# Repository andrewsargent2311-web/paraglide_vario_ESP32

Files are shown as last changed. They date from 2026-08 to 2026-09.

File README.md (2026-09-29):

# Paraglide Vario / Flight Computer (ESP32-S3)

A DIY flight computer for paragliding and paramotoring that costs about **$60 USD** in parts. It has a sunlight-readable screen, a climb/sink beeper (vario), GPS, a barometer, airspace warnings, live ADS-B traffic with spoken voice alerts, weather stations, FANET radio and IGC flight logging.

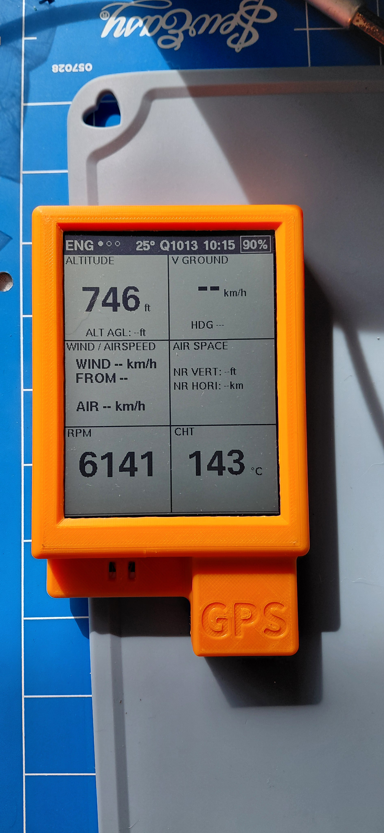
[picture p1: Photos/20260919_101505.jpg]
The finished flight computer


**You do not need any electronics or programming experience.** This guide walks through every step. If you can follow a recipe and are willing to learn to solder a few small parts (or find a friend who can), you can build this.

> ⚠️ **Safety:** This is a hobby project, not a certified flight instrument. Never rely on it as your only source of airspace, altitude or traffic information. Test everything on the ground before you fly with it.

---

## Contents

1. [What it does](#1-what-it-does)
2. [What you need to buy](#2-what-you-need-to-buy)
3. [Tools you need](#3-tools-you-need)
4. [Step 1: Order the circuit board](#step-1-order-the-circuit-board)
5. [Step 2: 3D print the case](#step-2-3d-print-the-case)
6. [Step 3: Solder the circuit board](#step-3-solder-the-circuit-board)
7. [Step 4: Install the software tools](#step-4-install-the-software-tools)
8. [Step 5: Add your WiFi details](#step-5-add-your-wifi-details)
9. [Step 6: Upload the code](#step-6-upload-the-code)
10. [Step 7: Prepare the SD card](#step-7-prepare-the-sd-card)
11. [Step 8: Assemble everything](#step-8-assemble-everything)
12. [Step 9: First power-on check](#step-9-first-power-on-check)
13. [How to use it](#how-to-use-it)
14. [Voice traffic alerts](#voice-traffic-alerts)
15. [Cloud base estimate](#cloud-base-estimate)
16. [Optional extras](#optional-extras)
17. [Troubleshooting](#troubleshooting)
18. [Using it outside New Zealand](#using-it-outside-new-zealand)
19. [Code layout](#code-layout)
20. [Credits](#credits)

---

## 1. What it does

- **Vario:** beeps faster and higher as you climb, lower tones when you sink
- **Main flight screen:** altitude, height above ground (AGL), ground speed, heading, QNH, battery
- **Airspace:** warns you about nearby controlled airspace from an OpenAIP file
- **Cloud base estimate:** a rough guess of how high the cloud base is, worked out from the temperature, humidity and pressure sensors (see [Cloud base estimate](#cloud-base-estimate))
- **ADS-B page:** shows nearby aircraft on a radar-style display
- **Voice traffic alerts:** when an aircraft comes close, the speaker tells you where it is, e.g. *"Aircraft on your two o'clock, flying north west, at two thousand four hundred feet, one thousand two hundred feet above you, and is eight hundred meters away."* You can switch this to a siren, or turn it off (see [Voice traffic alerts](#voice-traffic-alerts))
- **Weather page:** wind from nearby weather stations (Zephyr) or from FANET
- **FANET:** sends and receives FANET radio messages, with preset messages you can broadcast
- **IGC flight logging** to the SD card, downloadable over WiFi
- **Optional:** connects by Bluetooth to a separate engine meter (RPM, cylinder temperature) for paramotor use

**One button** controls everything (see [How to use it](#how-to-use-it)).

## 2. What you need to buy

| Part | Approx. cost | Notes |
|---|---|---|
| [Waveshare ESP32-S3-RLCD-4.2](https://www.waveshare.com/esp32-s3-rlcd-4.2.htm) | $27 | The "brain", screen, speaker driver, SD slot and battery holder all in one |
| [Adafruit BMP580](https://www.adafruit.com/product/6411) | $8 | Barometer, measures altitude change for the vario |
| [Waveshare LC76G GNSS module](https://www.waveshare.com/lc76g-gnss-module.htm) | $15 | GPS |
| Custom circuit board (PCB) from PCBWay | $5 | See [Step 1](#step-1-order-the-circuit-board) |
| 3D printer filament (PLA) | $5 | Orange in the photos, any colour works |
| microSD card, 8–16 GB | a few $ | Doesn't need to be bigger |
| **HT-RA62 LoRa radio module** | check price | Soldered directly onto the PCB, used for FANET. *Not included in the original $60 estimate.* |
| **18650 lithium battery** | check price | Fits in the holder on the Waveshare board. Use a good-quality protected cell. |
| **Small speaker** with an MX1.25 2-pin plug | a few $ | Plugs into the Waveshare board's speaker header. Without it there is no vario sound. |
| **USB-C data cable** | | Must carry data, not just charge |

**Small parts for the PCB** (all size 0805 surface-mount):

| Qty | Part |
|---|---|
| 2 | 100 nF capacitor |
| 2 | 10 µF capacitor |
| 1 | 10 kΩ resistor |

You will also need some pin headers and/or sockets to connect the Waveshare board, BMP580 and GPS module to the PCB. The exact layout is shown in the [KiCad project](PCB%20files/ESP32%20vario_PCB_layout/).

**Total: roughly $60–80 USD** plus shipping, depending on the items in bold.

> **Tip:** Buy everything from the same order window if you can. PCBs from PCBWay usually arrive in a couple of weeks, so order that first.

## 3. Tools you need

- **Soldering iron** with a fine tip, solder and flux (for the tiny 0805 parts and the LoRa module). A hot-air station makes this easier but is not required.
- **Tweezers** (for the small parts)
- **A 3D printer**, or use a print service / friend with one
- **A computer** (Windows, Mac or Linux) with a USB port
- **A microSD card reader**
- Small screwdrivers, and wire cutters

**Never soldered before?** The only genuinely fiddly parts are the 0805 capacitors/resistor and the HT-RA62 module. Watch a couple of "how to solder SMD 0805" videos and practise on a spare board first, or ask a local maker space or electronics-savvy friend to do just those parts.

**Time:** allow a weekend. The 3D printing (about 9.5 hours total) runs by itself.

---

## Step 1: Order the circuit board

The circuit board (PCB) connects all the modules together so you don't have to wire anything by hand.

1. Go to [pcbway.com](https://www.pcbway.com) and choose **Instant Quote**.
2. Upload the file [`PCB files/Gerber Files V2/ESP32 vario-B_PCB_.zip`](PCB%20files/Gerber%20Files%20V2/). It contains all the Gerber and drill files in one zip.
3. Leave the options at their defaults unless you have a preference (it is a simple two-layer board), and place the order.

The original design files (KiCad) are in [`PCB files/ESP32 vario_PCB_layout/`](PCB%20files/ESP32%20vario_PCB_layout/) if you want to modify the board.

## Step 2: 3D print the case

All files are in [`3D print Files/`](3D%20print%20Files/).

| Part | STL file | Print time (0.15 mm PLA, Prusa MK3S) |
|---|---|---|
| Main case | `Flight computer main case.stl` | 5 h 49 m |
| Back plate | `Flight computer back plate.stl` | 2 h 11 m |
| Base plate | `Flight computer base plate.stl` | 1 h 14 m |
| Button | `button.stl` | 8 m |
| Button (short) | `button_Short.stl` | 6 m |
| Button (long) | `button_Long.stl` | 9 m |

- If you have a **Prusa MK3S**, you can print the ready-made G-code in the `Prusa slicer G code` folder.
- For **any other printer**, open the `.stl` files in your printer's slicing software (Cura, PrusaSlicer, Bambu Studio, etc.) and use normal PLA settings at 0.15 mm layer height.
- Print all three buttons; you'll pick whichever length feels best when you assemble it.

## Step 3: Solder the circuit board

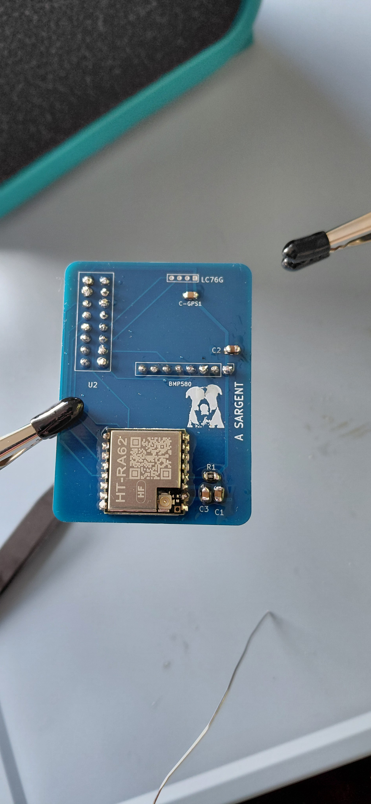
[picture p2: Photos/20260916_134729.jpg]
The PCB with the LoRa module fitted


Work from the smallest parts to the biggest, and take your time. Solder joints should be shiny and cone-shaped, not blobs.

1. **Small surface-mount parts first:** the two 100 nF capacitors, two 10 µF capacitors and the 10 kΩ resistor. The reference labels (C1, C2, C3, C-GPS1, R1) are printed on the board. Use the [parts list](PCB%20files/ESP32%20vario_PCB_layout/ESP32%20vario.csv) to match them.
2. **HT-RA62 LoRa module (U1):** solder this onto its pads on the board. Check the orientation using the silkscreen and the photo above. Double-check no pins are bridged with solder.
3. **Headers:** solder the pin headers/sockets for the Waveshare board (U2), BMP580 (U3) and GPS (U4).
4. **Plug in the modules.** Make sure each one goes the right way round. Use the photos in [`Photos/`](Photos/) as a reference.

**Before going on, check:** with a magnifier, look at every solder joint for bridges (solder connecting two neighbouring pins) and for pins that missed the solder.

## Step 4: Install the software tools

This is the same every time you set up an ESP32 board, and it's easier than it sounds.

### 4.1 Install the Arduino IDE
Download **Arduino IDE 2** from [arduino.cc/en/software](https://www.arduino.cc/en/software) and install it.

### 4.2 Add ESP32 support
1. Open the Arduino IDE → **File → Preferences**.
2. In **Additional boards manager URLs**, paste: `https://espressif.github.io/arduino-esp32/package_esp32_index.json`
3. Click **OK**, then open **Tools → Board → Boards Manager**.
4. Search for **esp32** and install **"esp32 by Espressif Systems"**.

### 4.3 Download this project
On this GitHub page, click the green **Code** button → **Download ZIP**, then unzip it somewhere you can find it (for example your Documents folder).

### 4.4 Install the libraries
Libraries are add-on code the project uses. Install these from **Sketch → Include Library → Manage Libraries…** by searching for each name:

| Library | Author |
|---|---|
| Adafruit BMP5xx | Adafruit |
| Adafruit SHTC3 | Adafruit |
| Adafruit Unified Sensor | Adafruit |
| TinyGPSPlus (shown as "TinyGPSPlus") | Mikal Hart |
| ArduinoJson | Benoit Blanchon |
| NimBLE-Arduino | h2zero |
| RadioLib | Jan Gromeš |
| PCF85063A (search "PCF85063A"; the clock library, by Soldered) | Soldered |

When the IDE asks *"Install all dependencies?"*, click **Install all**.

**The screen library (U8g2) needs special handling.** This project uses a version that supports the Waveshare screen:

1. Download Waveshare's repository as a ZIP: [github.com/waveshareteam/ESP32-S3-RLCD-4.2](https://github.com/waveshareteam/ESP32-S3-RLCD-4.2) → **Code → Download ZIP**.
2. Unzip it and open the folder `01_Arduino_Libraries`.
3. Copy the folder named **`U8g2`** into your Arduino libraries folder. On Windows this is `Documents\Arduino\libraries`; on Mac it's `Documents/Arduino/libraries`.
4. If you previously installed "U8g2" from the Library Manager, delete or uninstall it first, so there's only one copy.
5. Restart the Arduino IDE.

> The other libraries in that Waveshare folder (SensorLib, LVGL) aren't needed for this project.

## Step 5: Add your WiFi details

The code expects a file called `secrets.h` containing your WiFi network names and passwords. It is deliberately not uploaded to GitHub (so passwords don't leak), so you have to create it.

1. In the project folder, open `paraglide_vario_ESP32/` (the folder with `paraglide_vario_ESP32.ino` in it).
2. Copy the file **`secrets.example.h`** and rename the copy to **`secrets.h`**.
3. Open `secrets.h` in any text editor and put in your details, for example:

```cpp
static const WifiNetwork WIFI_NETWORKS[WIFI_NETWORK_COUNT] = {
  { "MyHomeWiFi",     "my-home-password" },
  { "MyPhoneHotspot", "hotspot-password" },
  { "",               "" },
};
```

- Use a **2.4 GHz** network. The ESP32 can't connect to 5 GHz WiFi.
- Leave unused slots as empty quotes `""`.
- A **phone hotspot** is handy at the launch site, since that's how the ADS-B traffic and weather pages get their data in the field.

## Step 6: Upload the code

1. In the Arduino IDE, open **`paraglide_vario_ESP32/paraglide_vario_ESP32.ino`**.
2. Plug the Waveshare board into your computer with the USB-C cable.
3. Go to **Tools** and set these exactly (they match Waveshare's own recommended settings):

| Setting | Value |
|---|---|
| Board | **ESP32S3 Dev Module** |
| USB CDC On Boot | **Enabled** |
| Flash Mode | **QIO 80MHz** |
| Flash Size | **16MB (128Mb)** |
| Partition Scheme | **16M Flash (3MB APP/9.9MB FATFS)** |
| PSRAM | **OPI PSRAM** |
| Upload Speed | 921600 |

4. Under **Tools → Port**, choose the port that appeared when you plugged the board in (COM-something on Windows, `/dev/cu.usbmodem…` on Mac).
5. Click the **Upload** button (the right-pointing arrow). The first build takes a few minutes.
6. When it says **"Done uploading"**, the code is on your device.

If the upload doesn't start, hold the **BOOT** button on the board, tap **RESET**, then release BOOT, and try again.

## Step 7: Prepare the SD card

1. **Format** the microSD card as **FAT32**.
2. Copy the files you want from [`paraglide_vario_ESP32/Goes into SD card/`](paraglide_vario_ESP32/Goes%20into%20SD%20card/) onto the **root** of the card. The two files go straight onto the card, but the **`VOICE` folder must be copied as a folder**, with the clips inside it:

| File / folder | What it's for |
|---|---|
| `AIRSPACE.txt` | Airspace data, used for warnings |
| `Lower_North_Island.ADEM` | Terrain height map, used to work out your height above ground (AGL). It's about 99 MB. |
| `VOICE/` (folder) | The 60 short speech clips (`V000.PCM` to `V059.PCM`, about 1.25 MB in total) used for [voice traffic alerts](#voice-traffic-alerts). The card must end up with `/VOICE/V000.PCM`, `/VOICE/V001.PCM` and so on. |

3. Eject the card safely and put it into the microSD slot on the Waveshare board.

**Notes:**
- The vario still works without the SD card, but you won't get flight logs, maps, airspace or voice alerts.
- All 60 voice clips must be present. If the `VOICE` folder or any single clip is missing, voice alerts are switched off (the rest of the unit works normally). `manifest.txt` in that folder is just a list of what each clip says. You don't need to copy it.
- You can keep several `.ADEM` maps on the card and choose between them from the menu (**Map**).
- The included airspace and terrain files cover the lower North Island of New Zealand. See [Optional extras](#optional-extras) for other areas.
- An optional splash image can be shown at startup: a file called `ROY.BIN` in the card root. If it's missing, a plain text splash screen is shown instead, so you can skip this.

## Step 8: Assemble everything

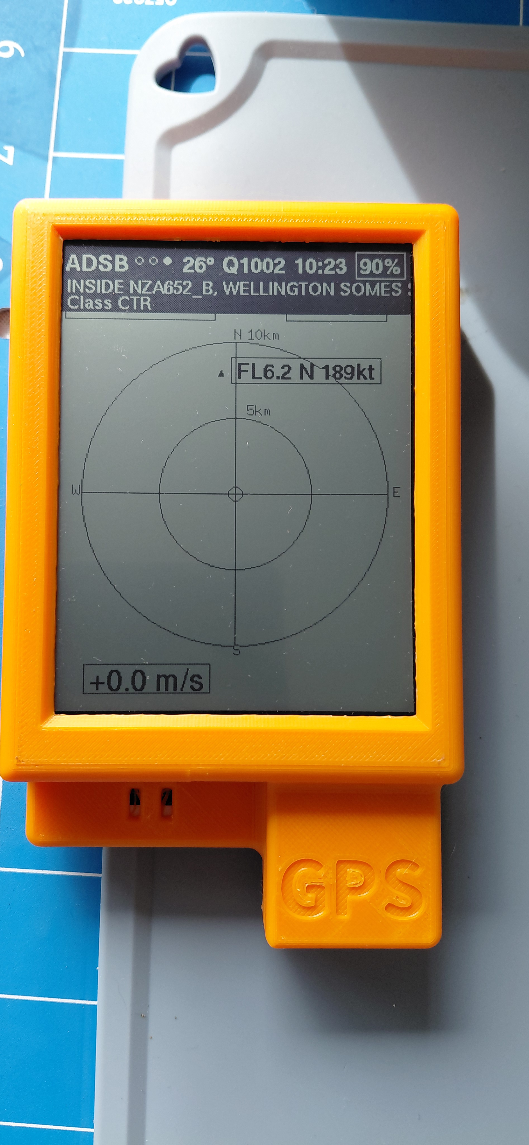
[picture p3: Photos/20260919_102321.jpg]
Assembled unit


1. Fit the **18650 battery** into the holder on the Waveshare board (check the +/− direction printed on the holder).
2. Plug the **speaker** into its 2-pin socket.
3. Push the Waveshare board onto the PCB, making sure the pins are lined up.
4. Connect the GPS and BMP580 modules to the PCB, and attach the antenna to the LoRa module.
5. Fit the board sandwich into the 3D-printed **main case**, then close it with the **back plate** and **base plate**.
6. Push the printed **button** into place over the button on the board. Try the three button lengths and use whichever feels best.

The GPS "bump" on the case (marked "GPS") should face the sky when you hold the unit flat, so the GPS gets a clear view.

Look at the photos in the [`Photos/`](Photos/) folder if you're unsure how something fits.

## Step 9: First power-on check

Do this indoors first, then repeat outside.

1. Switch on / plug in the unit. The **splash screen** appears for about 3 seconds, then the main screen.
2. Move the unit up and down by about a metre. You should hear the **vario beep** and see the altitude change.
3. Take it **outside with a clear view of the sky**. The first GPS lock can take a few minutes. Once it locks, speed, heading and time appear.
4. Look at the **AIR SPACE** box on the main screen. After the first temperature/humidity reading (about 10 seconds) and once the GPS has calibrated the altitude, the **CLD BASE** line shows a number. Until then it shows `--`. See [Cloud base estimate](#cloud-base-estimate) to calibrate it.
5. To see what the device is doing while it boots, open **Tools → Serial Monitor** in the Arduino IDE (baud rate **115200**) while the unit is plugged into your computer. It prints messages showing whether the SD card, barometer, GPS and radio all started correctly. If the voice clips loaded you will see `[Voice] Loaded 60 voice clips into PSRAM`.

---

## How to use it

The unit has **one button**:

| Menu | Press | What happens |
|---|---|---|
| Closed | **Short press** | Switch to the next page (Glider → Wind → ADS-B) |
| Closed | **Double press** | Open the menu |
| Closed | **Hold ~3–4 seconds** | Mute / unmute the vario |
| Open | **Short press** | Move down to the next menu item |
| Open | **Hold ~2 seconds** | Select the highlighted item |

**Menu contents**

- **Config:** time zone, units (altitude / speed), vario pitch, volume, screen orientation
- **Connections:** WiFi on/off and network choice, Bluetooth (engine meter), FANET on/off, FANET preset messages
- **Map:** choose which terrain map to use
- **ADS-B settings:** alert radius and vertical threshold, auto-jump to the ADS-B page, **Alarm Sound** (Off / Alarm / Voice), **Alert Volume**, range rings, airspace bars
- **Weather settings:** update interval, number of stations, data source
- **Flight recordings:** recording on/off, **Export files** (see below)

**Flight logs:** the unit automatically starts recording an `.IGC` file when you start moving (above about 10 km/h for 10 seconds). To download logs, open **Flight recordings → Export files**. Once the unit is connected to WiFi it shows a web address (something like `http://192.168.x.x/`). Open that in a browser on a phone or computer on the same network and click the file to download.

---

## Voice traffic alerts

When ADS-B shows an aircraft close to you, the unit can **speak** the warning (or sound a siren) as well as showing it on screen. For example:

> *"Aircraft on your two o'clock, flying north west, at two thousand four hundred feet, one thousand two hundred feet above you, and is eight hundred meters away."*

**Turning it on and setting it up** (all under **Config → ADSB Settings**):

| Item | What it does |
|---|---|
| **Alarm Sound** | Select it (hold the button ~2 seconds) to cycle **Off → Alarm → Voice**; each select moves it to the next mode. *Alarm* is the two-tone siren (5 seconds). *Voice* speaks the sentence above. *Off* mutes both. |
| **Alert Volume** | How loud the alert is, 0–100% in 10% steps. It applies to whichever of Alarm or Voice is selected. Select **Test** at the bottom of the list to hear it (it plays the example sentence above). It deliberately does not play a preview each time you scroll, because the full sentence takes about 5 seconds. |
| **Alert Radius** | How close, sideways, an aircraft must be to trigger an alert: 3, 5, 8 or 10 km (default 5). |
| **Vertical Threshold** | How close, up or down, it must be: 1000, 1500, 2000 or 3000 ft (default 2000). |
| **Auto-Jump** | Whether a new aircraft also switches the screen to the ADS-B page. This only changes the screen. The audio alert happens either way. |

**What it tells you, in order:**

1. **Where it is** as a clock position relative to the direction you are travelling (12 o'clock is straight ahead, 3 is to your right, 9 to your left).
2. **Which way it is flying** as a compass direction (north, north east, and so on). If the aircraft isn't broadcasting a heading it says *"heading unknown"*.
3. **Its altitude**, rounded to the nearest 100 ft.
4. **How far above or below you** it is, rounded to the nearest 100 ft.
5. **How far away** it is: in metres (nearest 100) when it is under 2 km, or in whole kilometres from 2 km up.

**When it speaks:**
- **Straight away** when a new aircraft enters your alert radius and vertical band.
- **Again every 60 seconds** for as long as an aircraft is still inside that zone. Each alert restarts the 60-second wait.
- It always describes the **nearest** aircraft, which is not necessarily the one that triggered the alert.
- It plays over the vario tone while it is speaking, and the vario carries on afterwards.

**Good to know:**
- **It needs a GPS fix and for you to be moving.** The clock position is worked out from your direction of travel, so with no valid GPS course (for example standing still on the ground, or before the first fix) the voice alert stays silent rather than guess. The siren does not have this limit.
- **It needs the SD card with the `VOICE` folder** (see [Step 7](#step-7-prepare-the-sd-card)) and **PSRAM enabled** in the Tools settings (see [Step 6](#step-6-upload-the-code)). The clips are loaded into memory once at start-up, so nothing is read from the card while an alert is playing.
- ADS-B data arrives over WiFi, so the alert only works when the unit is connected (for example to your phone hotspot). See the notes on ADS-B in [Step 5](#step-5-add-your-wifi-details).
- Like the rest of this project it is an aid, not a safety system. Keep looking around.

## Cloud base estimate

The **AIR SPACE** box on the Glider and Paramotor pages has a third line under the nearest-airspace distances:

```
NR VERT: 3200ft
NR HORI: 4.5km
CLD BASE: 4200ft
```

**What it means:** a rough estimate of the height of the cloud base, shown as an altitude above sea level in your chosen units, so you can compare it directly with your altitude reading. It shows `--` until the altitude is calibrated, and `0` means you are at or inside cloud.

**How it works:** the temperature and humidity sensor on the Waveshare board gives the *dew point*. The gap between the air temperature and the dew point tells you how far the air has to rise before it cools enough to form cloud (roughly 125 m of height per 1°C of gap). The barometer's pressure reading is used to convert that into a height. It updates every 10 seconds and is smoothed so the number doesn't jump around.

**Good to know:**
- It is a **rough guide**, best for daytime cumulus-type conditions where the air is well mixed. It is not meaningful in stable or layered conditions, and it becomes less accurate the higher the base is.
- Don't rely on it as your only source of cloud information.
- The sensor is inside the case, so it lags behind the real air when conditions change quickly.

### Calibrate it (recommended)

The temperature sensor sits next to the processor and battery, so it reads **warmer than the outside air**. This makes the cloud base read **too high**, by about **125 m for every 1°C** of error. You can fix this with one number:

1. Switch the unit on and leave it for about **10 minutes** so it warms up to normal.
2. Compare the temperature on the unit with a trusted thermometer (or a nearby weather station) in the same conditions. Ideally do this outdoors, in the shade.
3. Work out the difference. For example, the unit says 24°C and the thermometer says 21°C, so the difference is **3.0**.
4. In the Arduino IDE, open the **`AuxSensors.h`** tab and use **Edit → Find** to search for `SHT_SELF_HEAT_OFFSET_C`.
5. Change the number after it (the default is `0.0f`), for example:

```cpp
#define SHT_SELF_HEAT_OFFSET_C 3.0f
```

6. Click **Upload** again (see [Step 6](#step-6-upload-the-code)).

The dew point is not affected by the self-heating, so only this one number needs adjusting. If you can, compare the estimate against real cloud bases on a few flights and adjust the offset until it looks right.

The estimate needs no extra parts or libraries. It uses the sensors already on the board and is calculated in the `CloudBase.h` file in the code folder.

---

## Optional extras

### Get airspace for your own area
1. Go to [openaip.net](https://www.openaip.net/) and crop the airspace for your region.
2. Export it in **OpenAir `.txt`** format.
3. Rename it **`AIRSPACE.txt`** and put it in the root of the SD card, replacing the old one.
4. Very large files can cause problems. Crop to a sensible area around where you fly.

### Get more terrain maps
- Ready-made maps are in this shared folder: [Google Drive maps](https://drive.google.com/drive/folders/18hl1OCvvLns53WSxIf6_7ccbEHTFu314?usp=sharing). Download the `.ADEM` file you want and copy it to the SD card.
- To make your own from a New Zealand LINZ elevation download (GeoTIFF), use the Python script [`dem_to_agldem.py`](paraglide_vario_ESP32/dem_to_agldem.py). The script's comments explain how it works.

### Engine meter (paramotor)
The [`Engine_meter/`](Engine_meter/) folder contains a separate project (nRF52840-based) that measures RPM and cylinder head temperature and sends them to the flight computer over Bluetooth. It is not needed for paragliding.

---

## Troubleshooting

| Problem | Try this |
|---|---|
| **Can't find a COM port / upload won't start** | Use a USB cable that carries data (many are charge-only). Hold BOOT, tap RESET, release BOOT, then upload again. |
| **Error: `secrets.h: No such file or directory`** | You skipped [Step 5](#step-5-add-your-wifi-details). Copy `secrets.example.h` to `secrets.h`. |
| **Error about `PCF85063A.h`, `U8g2` or another missing file** | A library isn't installed. Go back to [Step 4.4](#44-install-the-libraries). |
| **Error mentioning `U8G2_ST7305_300X400…`** | The wrong U8g2 is installed. Use the copy from Waveshare's repo (see Step 4.4). |
| **Screen stays blank or code crashes on boot** | Check the Tools settings in Step 6, especially **PSRAM: OPI PSRAM** and **Flash Size: 16MB**. |
| **No sound** | Check the speaker is plugged in and the vario isn't muted (hold the button ~3 s). Check volume in **Config → Volume**. Traffic alerts have their own level in **ADSB Settings → Alert Volume**. |
| **No GPS fix** | Go outside with a clear view of the sky and wait a few minutes. Check the GPS module's soldering and that the case doesn't block it. |
| **No voice alert (siren works, or nothing plays)** | Check **Config → ADSB Settings → Alarm Sound** is set to **Voice** (not Alarm or Off) and the Alert Volume isn't 0%. Then check the Serial Monitor at boot for `[Voice] Loaded 60 voice clips into PSRAM`. |
| **Serial Monitor says `[Voice] /VOICE folder not found` or `Missing clip file`** | The `VOICE` folder must sit in the root of the SD card with all 60 clips in it (`V000.PCM` to `V059.PCM`). Copy the whole folder again. |
| **Serial Monitor says `[Voice] PSRAM allocation failed`** | Set **Tools → PSRAM → OPI PSRAM** and upload again (see [Step 6](#step-6-upload-the-code)). |
| **Voice alert works in the menu Test but never speaks in flight** | It stays silent until the GPS has a valid course, so you need a fix and to be moving. It also needs WiFi for the ADS-B data, and the aircraft must be inside your Alert Radius and Vertical Threshold. |
| **Altitude doesn't change / vario silent** | The BMP580 isn't being detected. Check its soldering and orientation. The Serial Monitor will report this on boot. |
| **SD card not detected** | Make sure it's FAT32, and files are in the root, not inside a folder. Try a different (smaller) card. |
| **WiFi won't connect** | 2.4 GHz only. Check the name and password in `secrets.h` match exactly (they're case-sensitive), then re-upload. |
| **CLD BASE shows `--`** | It needs a calibrated altitude (wait for a GPS fix) and a working barometer and temperature/humidity sensor. Give it about 10–20 seconds after start-up. |
| **CLD BASE reads much too high** | The temperature sensor is reading warm from the board's heat. Set `SHT_SELF_HEAT_OFFSET_C`; see [Cloud base estimate](#cloud-base-estimate). |
| **Menu doesn't open with a double press** | Press twice more quickly, or adjust the double-press timing in the code. |
| **No FANET / radio not working** | Check the HT-RA62 soldering and antenna. |

Still stuck? Open an **Issue** on this GitHub page, include what you were doing, what you expected and what happened, and copy in the messages from the Serial Monitor.

---

## Using it outside New Zealand

The code is set up for New Zealand, so a few things need changing elsewhere:

- **FANET radio frequency** is set to 868.2 MHz (NZ). Other regions differ (for example Australia uses the 915–928 MHz band). It's set where `fanetRadio.begin(` is called, which appears in both `paraglide_vario_ESP32.ino` and `FanetHandlers.cpp`, so change both. **Check your local rules before changing it.**
- **Weather stations** come from Zephyr (`api.zephyrapp.nz`), which only covers NZ. FANET weather still works anywhere.
- **Terrain maps** are built from NZ LINZ data. The conversion script would need different source data elsewhere.
- **Time zone** defaults to NZ (with daylight saving); you can set a fixed offset in **Config → Time**.
- **ADS-B** uses the worldwide adsb.fi service and airspace uses OpenAIP, so those work anywhere.
- **Voice alerts** are in English, in feet and metres/kilometres, and work anywhere. To change the words you would need to regenerate the 60 clips and `VoiceClips.h` together so they stay in step.

---

## Code layout

The firmware is split into one `.h`/`.cpp` pair per subsystem, all inside `paraglide_vario_ESP32/`. `paraglide_vario_ESP32.ino` holds only the includes, `setup()` and `loop()`. You don't need any of this to build the project, but it helps if you want to change something.

| File | What it does |
|---|---|
| `Buzzer` | Speaker and audio chip: vario beeps, sink tone, siren, mute jingle, and the voice alert trigger (`triggerAdsbAlert()`) |
| `VoiceAlert`, `VoiceClips.h` | Voice alerts: loads the 60 clips from the SD card into PSRAM at start-up, builds the spoken sentence and plays it |
| `AdsbClient` | Fetches and parses ADS-B traffic and works out which aircraft are threats |
| `Vario`, `WindEstimator` | Barometer, altitude and climb rate; wind estimate |
| `AuxSensors`, `CloudBase.h` | Battery, temperature/humidity sensor (cloud base estimate) and the clock |
| `FanetHandlers`, `Fanet`, `FanetMessaging`, `Sx126xLink` | FANET radio |
| `WeatherClient` | Weather station data |
| `Gps`, `SdCard`, `Display`, `IgcRecorder` | GPS object, SD card, screen, flight logging |
| `BackgroundTask` | The second processor core: WiFi, Bluetooth, web file server, ADS-B and weather polling, terrain and airspace lookups |
| `PageButton`, `menu`, `settings`, `DrawPages` | The single button, the menus, saved settings and drawing the pages |

## Credits

Designed and built by Andrew Sargent, including the PCB and case design. The code was written with help from Claude, GPT-5, Gemini and Copilot, plus code from other projects on GitHub. The voice alert clips were generated offline with the [Piper](https://github.com/rhasspy/piper) neural text-to-speech engine. Thanks to everyone whose open-source work this builds on.

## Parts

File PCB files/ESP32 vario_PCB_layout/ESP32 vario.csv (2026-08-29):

Reference | Qty | Value | DNP | Exclude from BOM | Exclude from Board | Footprint | Datasheet
C-GPS1 | 1 | 100n |  |  |  | Capacitor_SMD:C_0805_2012Metric
C1,C2-Bulk-cap1 | 2 | 10u |  |  |  | Capacitor_SMD:C_0805_2012Metric
C3 | 1 | 100n |  |  |  | Capacitor_SMD:C_0805_2012Metric_Pad1.18x1.45mm_HandSolder
R1 | 1 | 10K |  |  |  | Resistor_SMD:R_0805_2012Metric_Pad1.20x1.40mm_HandSolder
U1 | 1 | HT-RA62 |  |  |  | Flight cumputer footprints:HT-RA62
U2 | 1 | ESP32-S3 Waveshare |  |  |  | Flight cumputer footprints:ESP32-S3 Waveshare 16pin header | https://www.waveshare.com/esp32-s3-rlcd-4.2.htm
U3 | 1 | BMP580 |  |  |  | Flight cumputer footprints:BMP580 Header | https://learn.adafruit.com/adafruit-bmp580-bmp581-and-bmp585-temperature-and-pressure-sensor/pinouts
U4 | 1 | LC76G GPS |  |  |  | Flight cumputer footprints:LC76G- 4 pin

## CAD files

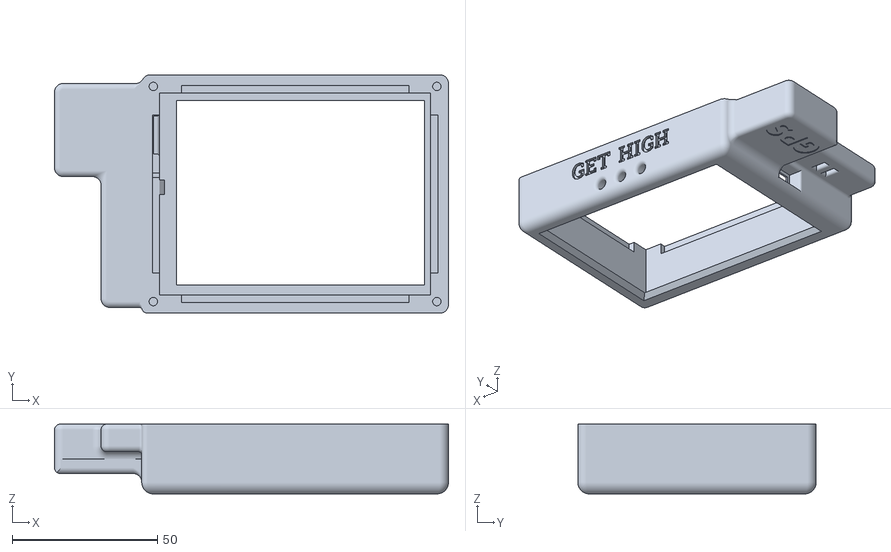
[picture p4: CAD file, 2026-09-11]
3D print Files/Flight computer main case.stl
135.5 x 82.0 x 24.0

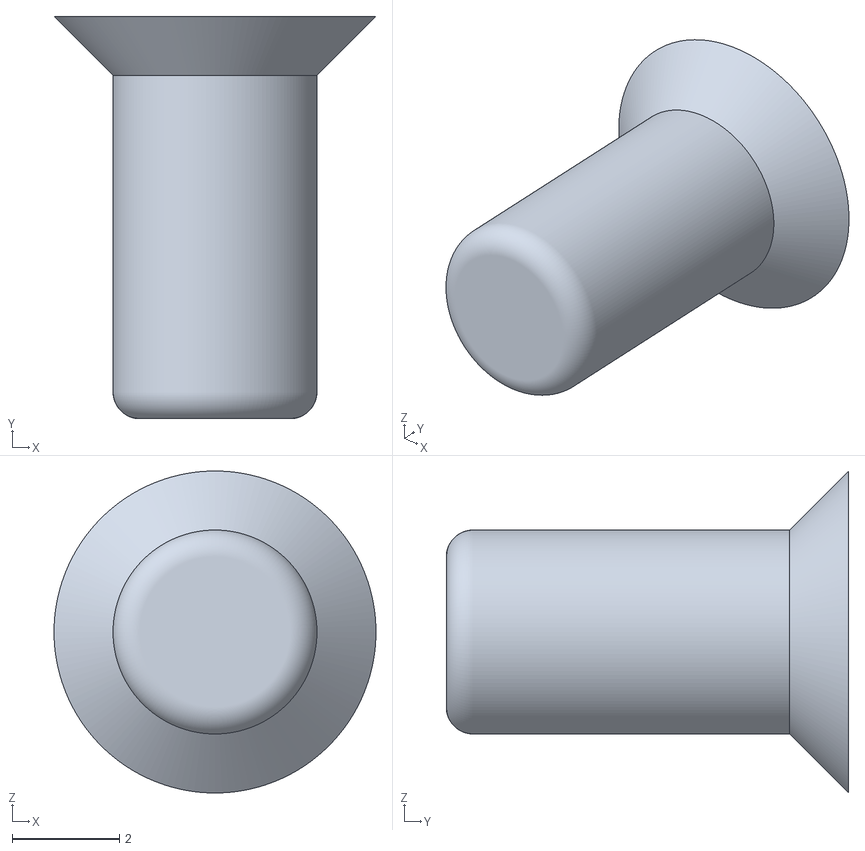
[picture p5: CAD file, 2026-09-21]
3D print Files/button_Long.stl
6.00 x 7.50 x 6.00

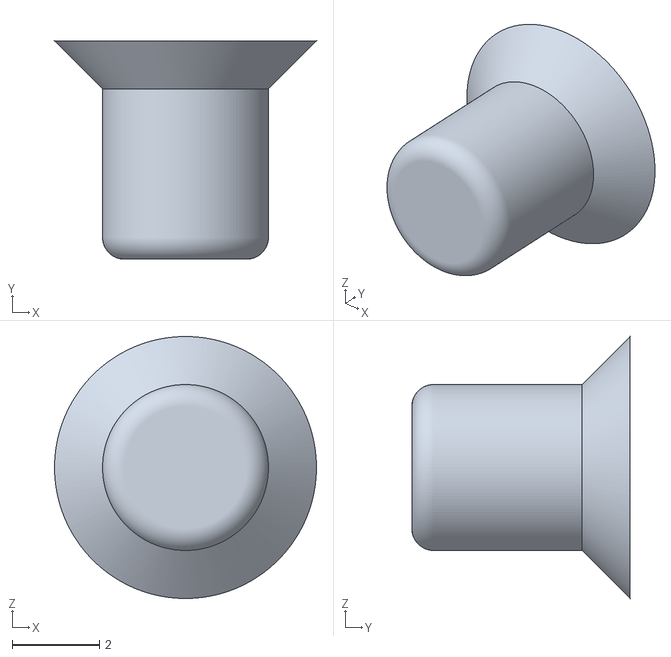
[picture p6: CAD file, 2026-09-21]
3D print Files/button_Short.stl
6.00 x 5.00 x 6.00

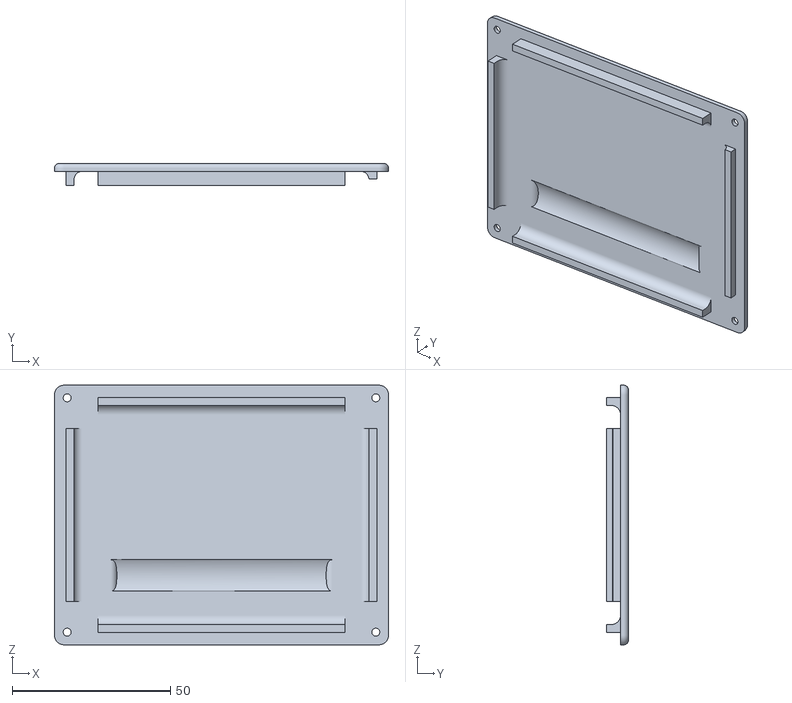
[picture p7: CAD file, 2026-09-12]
3D print Files/Flight computer back plate.stl
105.5 x 6.95 x 82.0

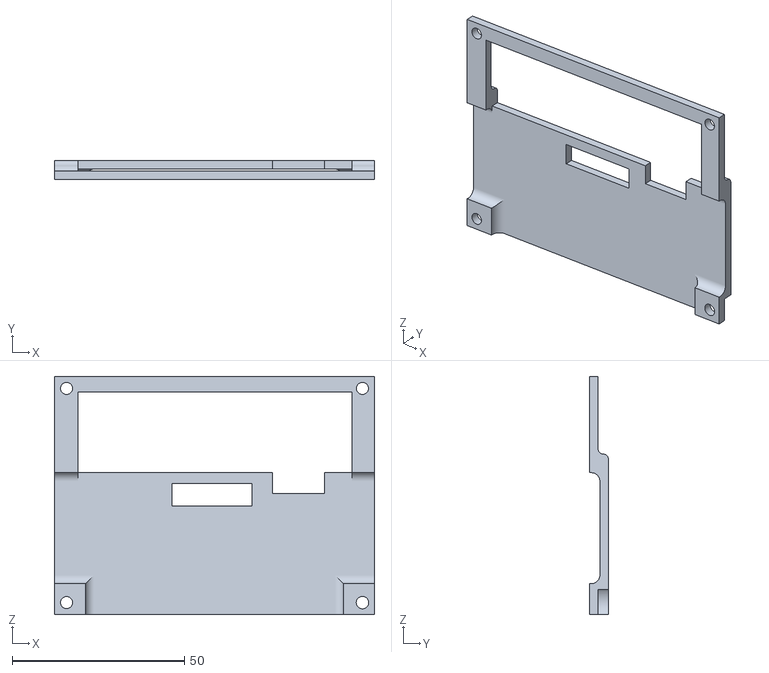
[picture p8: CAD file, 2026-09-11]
3D print Files/Flight computer base plate.stl
93.0 x 5.50 x 69.2

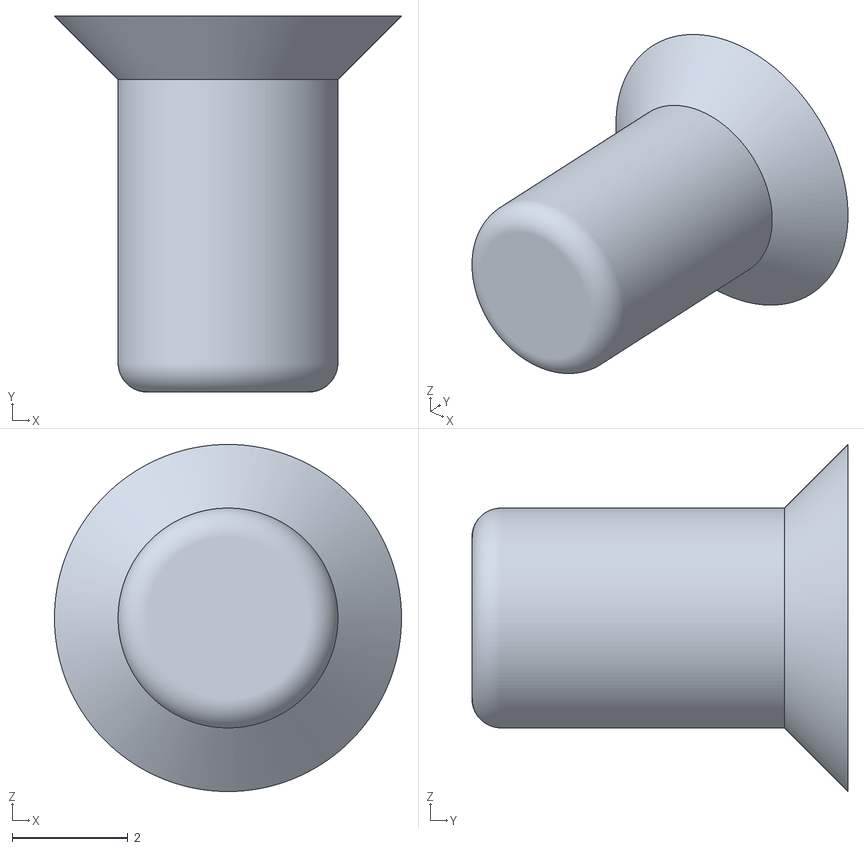
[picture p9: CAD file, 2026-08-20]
3D print Files/button.stl
6.00 x 6.50 x 6.00

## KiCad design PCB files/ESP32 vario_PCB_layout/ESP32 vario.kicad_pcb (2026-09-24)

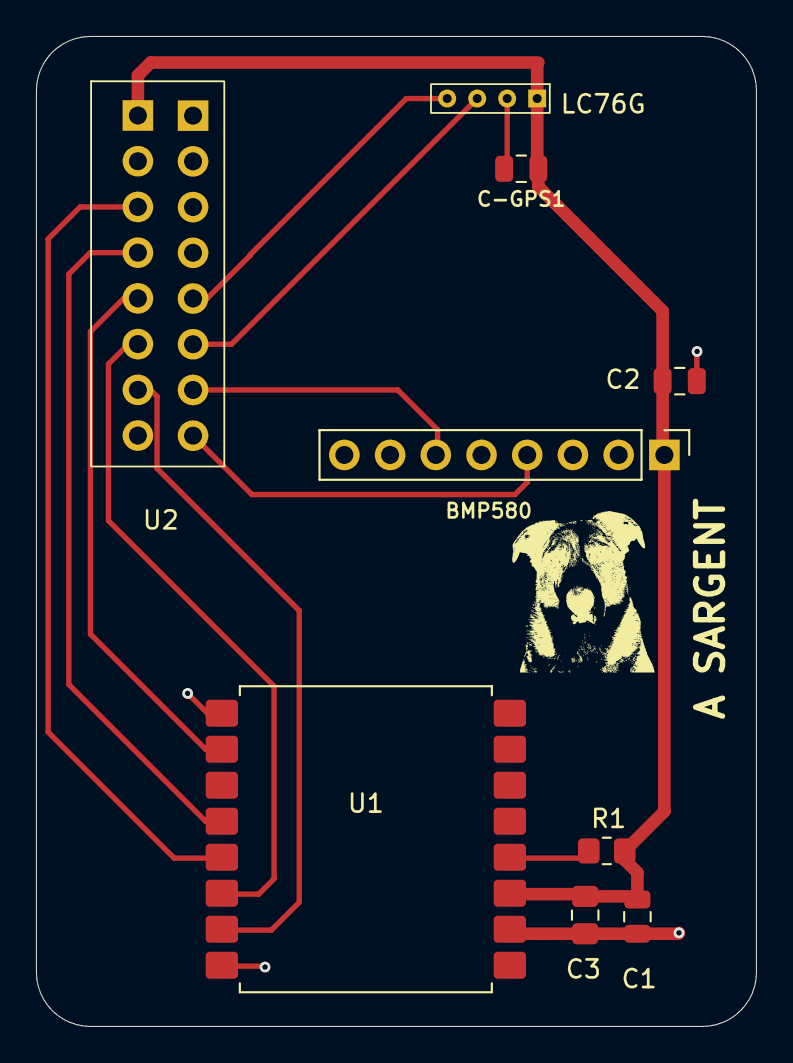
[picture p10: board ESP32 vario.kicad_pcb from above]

Board: 2 copper layers, 40.0 x 55.0 mm, 9 parts (0 on the bottom side), 12 nets.

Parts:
BMP580: BMP580; PinHeader_1x08_P2.54mm_Vertical
C1, C2: 10u; C_0805_2012Metric
C3: 100n; C_0805_2012Metric_Pad1.18x1.45mm_HandSolder
C-GPS1: 100n; C_0805_2012Metric
LC76G: LC76G GPS; LC76G- 4 pin
R1: 10K; R_0805_2012Metric_Pad1.20x1.40mm_HandSolder
U1: HT-RA62
U2: ESP32-S3 Waveshare; ESP32-S3 Waveshare 16pin header

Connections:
+3V: BMP580.1 (Vin), C1.2, C2.1, C3.2, C-GPS1.1, LC76G.1 (Vcc), R1.1, U1.3 (3V3), U2.1 (3V)
BUSY: U1.10 (BUSY), U2.5 (GP2)
GND: BMP580.3 (GND), C1.1, C2.2, C3.1, C-GPS1.2, LC76G.2 (GND), U1.2 (GND), U1.9 (GND), U1.16 (GND), U2.2 (GND), U2.10 (GND)
MISO: U1.13 (MISO), U2.3 (GP0)
MOSI: U1.14 (MOSI), U2.6 (GP3)
NSS(CS): U1.15 (NSS), U2.7 (GP17)
RST: R1.2, U1.4 (RST)
Rx: LC76G.3 (tX), U2.14 (Rx44)
SCK: U1.12 (SCK), U2.4 (GP1)
SCL: BMP580.4 (SCL), U2.16 (SCL)
SDA: BMP580.6 (SDA), U2.15 (SDA)
Tx: LC76G.4 (Rx), U2.13 (Tx43)

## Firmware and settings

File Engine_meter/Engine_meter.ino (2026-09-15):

// =====================================================================
// ENGINE METER firmware -- nice!nano (nRF52840)
// Reads RPM (inductive pickup -> LMV331 comparator) + dual MAX31856
// thermocouple channels (EGT + CHT), and streams the data over BLE
// to the paraglide_vario_ESP32 flight computer using the Nordic UART
// Service (NUS) -- the exact same service/characteristic the ESP32's
// ble_manager.cpp already scans for and subscribes to.
//
// Board: nice!nano (nRF52840), Adafruit nRF52 Arduino core
// Libraries needed (Library Manager):
//   - "Adafruit MAX31856 library" (by Adafruit)
//   - Bluefruit (bluefruit.h) ships with the Adafruit nRF52 BSP already
//
// Pin mapping traced from Engine_monitor_V1.kicad_sch. Adafruit's nRF52
// core numbers digital pins as: P0.xx -> pin xx, P1.xx -> pin (32+xx).
//
// *** CONTAINS TEMPORARY TEST CODE ***
// Search this file for "TEST CODE" -- there's a simulation mode that
// kicks in if no real RPM/CHT signal shows up within 45s of boot, so you
// can bench-test the BLE link to the vario without an engine attached.
// Delete it once real hardware is verified working.
// =====================================================================

#include <bluefruit.h>
#include <SPI.h>
#include <Adafruit_MAX31856.h>

// ---------------------------------------------------------------------
// PINS (from schematic global labels)
// ---------------------------------------------------------------------
#define PIN_SDO     32   // P1.00 -- MAX31856 SDO  -> MCU MISO (shared bus)
#define PIN_CS_CHT  11   // P0.11 -- MAX31856 #2 (CHT) chip select
#define PIN_CS_EGT  36   // P1.04 -- MAX31856 #1 (EGT) chip select
#define PIN_SCK     47   // P1.15 -- shared SPI clock
#define PIN_SDI     45   // P1.13 -- MCU MOSI -> MAX31856 SDI (shared bus)
#define PIN_RPM     43   // P1.11 -- comparator output (LMV331), pulled up by R8

// ---------------------------------------------------------------------
// RPM CONFIG
// ---------------------------------------------------------------------
// How many spark pulses per crank revolution the pickup sees.
// Most single-cylinder 2-stroke paramotor engines: 1 pulse/rev.
// Change to 0.5 for a twin sharing one kill lead, 2 for a wasted-spark
// 4-stroke twin that fires every pulse but only every 2nd is a power
// stroke, etc. -- tune this to what you actually observe.
#define PULSES_PER_REV        1.0f

// If no pulse has arrived in this long, report RPM = 0 (engine off/stalled)
// rather than showing a stale reading.
#define RPM_TIMEOUT_MS         1500

// ---------------------------------------------------------------------
// BLE -- Nordic UART Service, matching ble_manager.cpp on the ESP32 side
// ---------------------------------------------------------------------
BLEUart bleuart;  // Bluefruit's BLEUart *is* the Nordic UART Service --
                   // same service UUID (6E400001-...) and TX characteristic
                   // (6E400003-...) the ESP32 vario already looks for.

// ---------------------------------------------------------------------
// Thermocouple amps -- software SPI (bit-banged) so we can use the
// arbitrary GPIOs the board routes them on, sharing one SCK/SDI/SDO bus
// with separate chip-selects.
// ---------------------------------------------------------------------
Adafruit_MAX31856 maxEGT(PIN_CS_EGT, PIN_SDI, PIN_SDO, PIN_SCK);
Adafruit_MAX31856 maxCHT(PIN_CS_CHT, PIN_SDI, PIN_SDO, PIN_SCK);

// ---------------------------------------------------------------------
// RPM: measured from the period between pulses (captured in an ISR),
// not from a counted-pulses-per-window average -- this responds
// immediately to RPM changes instead of lagging behind a sample window.
// ---------------------------------------------------------------------
volatile uint32_t lastPulseUs = 0;
volatile uint32_t lastPeriodUs = 0;
volatile uint32_t lastPulseMillis = 0;

void rpmISR() {
  uint32_t now = micros();
  uint32_t period = now - lastPulseUs;
  // Basic debounce: ignore pulses closer together than 1ms (would imply
  // >30,000 RPM at 2 pulses/rev, well above anything realistic here).
  if (period > 1000) {
    lastPeriodUs = period;
    lastPulseUs = now;
    lastPulseMillis = millis();
  }
}

float readRpm() {
  noInterrupts();
  uint32_t period = lastPeriodUs;
  uint32_t sinceLastPulse = millis() - lastPulseMillis;
  interrupts();

  if (lastPulseMillis == 0 || sinceLastPulse > RPM_TIMEOUT_MS || period == 0) {
    return 0.0f;
  }
  float revsPerSec = (1000000.0f / period) / PULSES_PER_REV;
  return revsPerSec * 60.0f;
}

// ---------------------------------------------------------------------
// OUTGOING PACKET FORMAT
// Fixed 9-byte layout, well under the default ~20 byte NUS notify MTU.
// This is a starting-point protocol -- change it freely, just keep the
// ESP32-side decoder (which you'll add in bleReadLatestEngineData()'s
// caller / drawParamotorPage()) in sync with whatever you settle on.
//
//   byte 0    : 0xAE  sync/header byte
//   byte 1-2  : uint16_t RPM, little-endian
//   byte 3-4  : int16_t  EGT, little-endian, in 0.1 degC units
//   byte 5-6  : int16_t  CHT, little-endian, in 0.1 degC units
//   byte 7    : status flags (bit0 = EGT fault, bit1 = CHT fault)
//   byte 8    : checksum = XOR of bytes 0..7
// ---------------------------------------------------------------------
#define PKT_HEADER 0xAE

void sendEnginePacket(float rpm, float egtC, bool egtFault,
                       float chtC, bool chtFault) {
  uint8_t pkt[9];
  uint16_t rpmVal = (uint16_t)constrain(rpm, 0, 65535);
  int16_t egtVal = (int16_t)constrain(egtC * 10.0f, -3000, 30000);
  int16_t chtVal = (int16_t)constrain(chtC * 10.0f, -3000, 30000);

  pkt[0] = PKT_HEADER;
  pkt[1] = (uint8_t)(rpmVal & 0xFF);
  pkt[2] = (uint8_t)(rpmVal >> 8);
  pkt[3] = (uint8_t)(egtVal & 0xFF);
  pkt[4] = (uint8_t)(egtVal >> 8);
  pkt[5] = (uint8_t)(chtVal & 0xFF);
  pkt[6] = (uint8_t)(chtVal >> 8);
  pkt[7] = (egtFault ? 0x01 : 0x00) | (chtFault ? 0x02 : 0x00);

  uint8_t chk = 0;
  for (int i = 0; i < 8; i++) chk ^= pkt[i];
  pkt[8] = chk;

  if (Bluefruit.connected()) {
    bleuart.write(pkt, sizeof(pkt));
  }
}

// ---------------------------------------------------------------------
// BLE connect/disconnect callbacks -- just for a status LED / Serial log
// ---------------------------------------------------------------------
void connectCallback(uint16_t conn_handle) {
  BLEConnection* conn = Bluefruit.Connection(conn_handle);
  char name[32] = {0};
  conn->getPeerName(name, sizeof(name));
  Serial.print("[BLE] Connected to ");
  Serial.println(name);
}

void disconnectCallback(uint16_t conn_handle, uint8_t reason) {
  (void)conn_handle;
  (void)reason;
  Serial.println("[BLE] Disconnected -- advertising again");
}

void startAdv() {
  Bluefruit.Advertising.addFlags(BLE_GAP_ADV_FLAGS_LE_ONLY_GENERAL_DISC_MODE);
  Bluefruit.Advertising.addTxPower();
  Bluefruit.Advertising.addService(bleuart);
  Bluefruit.Advertising.addName();

  Bluefruit.Advertising.restartOnDisconnect(true);
  Bluefruit.Advertising.setInterval(32, 244);  // in units of 0.625ms
  Bluefruit.Advertising.setFastTimeout(30);
  Bluefruit.Advertising.start(0);              // 0 = never stop advertising
}

// =====================================================================
// ############################  TEST CODE  ############################
// SIMULATION MODE -- FOR BENCH TESTING ONLY, DELETE THIS WHOLE BLOCK
// (and the two call-outs to it in loop(), each marked the same way)
// BEFORE FLYING.
//
// If 45 seconds pass after boot with no real RPM pulses AND the CHT
// thermocouple channel is faulted (i.e. nothing's actually wired up --
// the normal state while this board is sitting on a bench away from an
// engine), this switches to feeding the ESP32 a fake but plausible-
// looking data stream instead of real sensor readings. The only point
// is to prove the BLE link and packet decode work end-to-end on the
// vario's Paramotor page without needing an engine running. It does NOT
// touch real sensor logic -- once you plug in a real pickup/thermocouple
// this condition never triggers and the board behaves exactly as before.
// =====================================================================
#define SIM_TRIGGER_DELAY_MS   45000UL
bool simulationMode = false;

void maybeEnterSimulationMode(float realRpm, bool realChtFault) {
  if (simulationMode) return;
  if (millis() < SIM_TRIGGER_DELAY_MS) return;
  if (realRpm > 0.0f || !realChtFault) return;  // real hardware looks present -- leave it alone

  simulationMode = true;
  Serial.println("[TEST] No RPM pulses / no CHT thermocouple detected after 45s -- "
                  "entering SIMULATION MODE (fake test data). "
                  "REMOVE maybeEnterSimulationMode()/generateSimulatedData() before flying!");
}

// Triangle-wave RPM (idle <-> redline over ~20s) and sine-wave CHT/EGT
// (over ~60s) -- just needs to move around convincingly on the display,
// doesn't need to be physically realistic.
void generateSimulatedData(float& rpm, float& egtC, bool& egtFault,
                            float& chtC, bool& chtFault) {
  const float RPM_MIN = 1200.0f, RPM_MAX = 6500.0f, RPM_PERIOD_MS = 20000.0f;
  float rpmPhase = fmodf(millis(), RPM_PERIOD_MS) / RPM_PERIOD_MS;  // 0..1
  float rpmTri = (rpmPhase < 0.5f) ? (rpmPhase * 2.0f) : (2.0f - rpmPhase * 2.0f);  // triangle 0..1..0
  rpm = RPM_MIN + rpmTri * (RPM_MAX - RPM_MIN);

  const float CHT_MIN = 70.0f, CHT_MAX = 150.0f, CHT_PERIOD_MS = 60000.0f;
  float chtSine = (sinf(2.0f * PI * millis() / CHT_PERIOD_MS) + 1.0f) / 2.0f;  // 0..1
  chtC = CHT_MIN + chtSine * (CHT_MAX - CHT_MIN);
  chtFault = false;

  const float EGT_MIN = 300.0f, EGT_MAX = 650.0f;
  egtC = EGT_MIN + chtSine * (EGT_MAX - EGT_MIN);  // rides the same phase as CHT, close enough
  egtFault = false;
}
// ##########################  END TEST CODE  ##########################

void setup() {
  Serial.begin(115200);
  // Uncomment while debugging on USB power if you want to see setup
  // logs before the vario is nearby to connect to:
  // while (!Serial) delay(10);

  // ---- RPM input ----
  pinMode(PIN_RPM, INPUT);  // external 10k pull-up (R8) already on board
  attachInterrupt(digitalPinToInterrupt(PIN_RPM), rpmISR, FALLING);

  // ---- Thermocouples ----
  maxEGT.begin();
  maxEGT.setThermocoupleType(MAX31856_TCTYPE_K);
  maxCHT.begin();
  maxCHT.setThermocoupleType(MAX31856_TCTYPE_K);

  // ---- BLE ----
  Bluefruit.begin();
  Bluefruit.setTxPower(4);
  Bluefruit.setName("ParaEngineMeter");  // shows up in the vario's BT scan list
  Bluefruit.Periph.setConnectCallback(connectCallback);
  Bluefruit.Periph.setDisconnectCallback(disconnectCallback);

  bleuart.begin();

  startAdv();
  Serial.println("[BOOT] Engine meter ready, advertising as ParaEngineMeter");
}

void loop() {
  static uint32_t lastSend = 0;
  const uint32_t SEND_INTERVAL_MS = 200;  // 5 Hz telemetry

  if (millis() - lastSend >= SEND_INTERVAL_MS) {
    lastSend = millis();

    float rpm = readRpm();

    float egtC = maxEGT.readThermocoupleTemperature();
    uint8_t egtFaultBits = maxEGT.readFault();
    bool egtFault = (egtFaultBits != 0);

    float chtC = maxCHT.readThermocoupleTemperature();
    uint8_t chtFaultBits = maxCHT.readFault();
    bool chtFault = (chtFaultBits != 0);

    // ---- TEST CODE: delete this call along with the block it calls
    // (maybeEnterSimulationMode/generateSimulatedData above) once you're
    // done bench-testing the BLE link. See the block comment above for
    // what this does and why. ----
    maybeEnterSimulationMode(rpm, chtFault);
    if (simulationMode) {
      generateSimulatedData(rpm, egtC, egtFault, chtC, chtFault);
    }
    // ---- END TEST CODE ----

    sendEnginePacket(rpm, egtC, egtFault, chtC, chtFault);

    Serial.printf("RPM=%.0f  EGT=%.1fC%s  CHT=%.1fC%s%s\n",
                  rpm, egtC, egtFault ? " [FAULT]" : "",
                  chtC, chtFault ? " [FAULT]" : "",
                  simulationMode ? "  [SIMULATED -- TEST DATA]" : "");
  }
}

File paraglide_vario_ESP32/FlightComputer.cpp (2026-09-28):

// v5 STABLE OPTIMISED: based on known-good v4; ADS-B remains loop-driven; no RTOS ADS-B task/mutex.
#include <Arduino.h>
#include <time.h>
#include <U8g2lib.h>
#include <TinyGPS++.h>
#include <Wire.h>
#include <SPI.h>
#include <Adafruit_Sensor.h>
#include <Adafruit_BMP5xx.h>
#include <Adafruit_SHTC3.h>
#include <WiFi.h>
#include <HTTPClient.h>
#include <WiFiClient.h>
#include <WiFiClientSecure.h>
#include <ArduinoJson.h>
#include <driver/i2s.h>
#include <math.h>
#include <string.h>
#include <esp_task_wdt.h>
#include <esp_timer.h>
#include <Preferences.h>  // climb/sink volume persistence (see loadVarioVolumes())
#include <FS.h>
#include <SD_MMC.h>
#include "secrets.h"
#include "OpenAirScanner.h"
#include "menu.h"
#include "settings.h"
#include "Sx126xLink.h"
#include "Fanet.h"
#include "FanetMessaging.h"
#include "wifi_manager.h"
#include "FileServer.h"
#include "DrawPages.h"
#include "CloudBase.h"
#include "VoiceAlert.h"
// --- split-out subsystems (see "Flight Computer - Source Layout.txt") ---
#include "Utils.h"
#include "CrossCoreState.h"
#include "Gps.h"
#include "SdCard.h"
#include "Display.h"
#include "AirspaceProximity.h"
#include "FanetHandlers.h"
#include "AuxSensors.h"
#include "WindEstimator.h"
#include "Vario.h"
#include "Buzzer.h"
#include "AdsbClient.h"
#include "WeatherClient.h"
#include "PageButton.h"
#include "IgcRecorder.h"
#include "BackgroundTask.h"

// =====================================================
// WIFI (feeds Weather + ADS-B pages) + BLUETOOTH (engine meter)
// Connection details (saved networks, remembered BLE device) live in
// secrets.h / wifi_manager.cpp / ble_manager.cpp, and are picked/managed
// from the Connections menu -- see menu.cpp. wifiConnected/bleConnected
// are declared in wifi_manager.h/ble_manager.h respectively.
// =====================================================

// =====================================================
// BMP580 BAROMETER (the actual vario sensor)
// =====================================================
#define I2C_SDA 13
#define I2C_SCL 14

// wifiConnected (wifi_manager.h) and bleConnected/bleEnabled
// (ble_manager.h) are the real connectivity state now -- see the
// Connections menu (menu.cpp) for where they're set.

void setup() {
  Serial.begin(115200);
  delay(1000);  // give the USB CDC host a moment to attach before the first print, or it's often lost
  Serial.println("BOOTING FLIGHT COMPUTER...");
  Serial.printf("[BOOT] Free heap: %u | Min heap: %u\n", ESP.getFreeHeap(), ESP.getMinFreeHeap());

  // Pull every persisted setting out of NVS before anything below reads
  // one of them (buzzer volume, climb tone, selected DEM file, etc.).
  loadSettings();
  loadVarioVolumes();  // climb/sink volume (Config > Vario Beep)
  activePages[0] = (mainPageSelection == 1) ? PAGE_PARAMOTOR : PAGE_PARAGLIDER;
  currentPage = activePages[0];
  Serial.println("[BOOT] Settings loaded from flash");

  // Heavy objects allocated here instead of as globals, so their
  // construction happens after the boot prints above are already
  // guaranteed to have gone out over serial -- if something about
  // allocating either of these ever goes wrong, you'll see exactly
  // where, instead of silence before setup() even starts.
  globalSecureWeatherClient = new WiFiClientSecure();
  Serial.printf("[BOOT] After adsbDoc/TLS client alloc - Free heap: %u | Min heap: %u\n",
                ESP.getFreeHeap(), ESP.getMinFreeHeap());

  // Attenuation must be set BEFORE the pin is ever read: analogRead()
  // attaches and configures the ADC1 channel on first use, and
  // reconfiguring attenuation on an already-attached channel leaves the
  // oneshot driver's channel handle in a bad state on this core, causing
  // every later analogReadMilliVolts() call in updateBattery() to fail
  // with "invalid channel". So: pinMode, then attenuation, then read.
  pinMode(BATT_ADC_PIN, INPUT);
  // Fire up the speaker power amplifier stage immediately at boot
  pinMode(AMP_ENABLE_PIN, OUTPUT);
  digitalWrite(AMP_ENABLE_PIN, LOW);  // Keep amplifier off during startup.
  analogSetPinAttenuation(BATT_ADC_PIN, ADC_11db);

  int raw = analogRead(BATT_ADC_PIN);
  Serial.print("Raw ADC test read: ");
  Serial.println(raw);

  setenv("TZ", NZ_TIMEZONE, 1);
  tzset();

  Serial1.begin(GPS_BAUD, SERIAL_8N1, GPS_RX_PIN, GPS_TX_PIN);
  Serial.println("GPS UART INITIALIZED");

  // ---------------------------------------------------------
  // Display + SD card brought up first, ahead of everything else that
  // used to sit in front of them, so the splash screen can be drawn as
  // early as possible. Previously the splash didn't appear until AFTER
  // the BMP test loop, RTC, FANET radio, and a blocking up-to-10s WiFi
  // connect attempt had all already run -- that's what made the screen
  // look "dead" for ~14s after power-on even though everything was
  // working fine the whole time (visible on Serial immediately).
  // ---------------------------------------------------------
  SPI.begin(RLCD_SCK, -1 /*MISO unused*/, RLCD_MOSI, RLCD_CS);
  u8g2.begin();
  applyScreenOrientation();  // screenOrientation was already loaded above by loadSettings()
  Serial.println("DISPLAY INITIALIZED");
  Serial.printf("[BOOT] After display - Free heap: %u | Min heap: %u\n", ESP.getFreeHeap(), ESP.getMinFreeHeap());

  // ESP32-S3 has no fixed default SDMMC pin set (unlike classic ESP32) --
  // pins must be assigned explicitly before begin(). Done here, ahead of
  // its old spot further down, purely so the splash image can be loaded
  // from SD before everything else runs.
  if (!SD_MMC.setPins(SD_MMC_CLK_PIN, SD_MMC_CMD_PIN, SD_MMC_D0_PIN)) {
    Serial.println("SD_MMC.setPins() failed");
  }
  sdCardOK = SD_MMC.begin("/sdcard", true);  // true = 1-bit mode (only D0 is wired)
  Serial.println(sdCardOK ? "SD CARD MOUNTED" : "SD CARD NOT FOUND -- IGC recording disabled");

  // Voice alert clips (see VoiceAlert.h) -- loads all 60 clips from
  // /VOICE/*.PCM into PSRAM once, up front, so real-time playback later
  // never has to touch the SD card. If this fails (missing folder,
  // missing PSRAM, etc.) voice alerts are just unavailable -- everything
  // else on the device still works normally.
  if (sdCardOK) {
    loadVoiceClips();
  }

  Serial.println("[BOOT] Drawing splash screen...");

  // Try to load the boot image from the SD card. Kept as a plain malloc'd
  // buffer scoped to setup() -- it's only needed for this one draw, so
  // there's no reason to keep ~7KB of RAM reserved for it afterwards.
  bool splashImageLoaded = false;
  uint8_t* splashBuf = nullptr;
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

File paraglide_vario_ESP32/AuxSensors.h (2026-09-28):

#pragma once
// AuxSensors -- three small, low-coupling subsystems in one file pair:
//   1. Battery monitor
//   2. SHTC3 ambient sensor (+ cloud base estimate)
//   3. Clock / hardware RTC
// Sensor/RTC init and the SHTC3 read stay inline in setup()/loop().
#include <Arduino.h>
#include <time.h>
#include <Adafruit_Sensor.h>
#include <Adafruit_SHTC3.h>
#include "PCF85063A.h"

// =====================================================
// BATTERY
// =====================================================
#define BATT_ADC_PIN 4
#define BATT_DIVIDER_RATIO 3.0f
#define BATT_EMPTY_V 2.5f
#define BATT_FULL_V 4.2f
#define BATT_SAMPLE_MS 2000
#define BATT_EMA_ALPHA 0.2f
extern float batteryVoltage;
extern uint8_t batteryPercent;
extern unsigned long lastBattSample;
extern bool battInitialized;
void updateBattery();

// =====================================================
// SHTC3 AMBIENT SENSOR (+ cloud base estimate)
// =====================================================
// The SHTC3 sits on the Waveshare board next to the ESP32 and battery, so it reads
// warmer than the outside air. Dew point is NOT affected by that (warming air doesn't
// change its moisture), but the air temperature is, and that would make the cloud base
// read too high (about +125 m per degree C of error). Set this to how many degrees C
// your unit reads above a trusted thermometer after it has been on for ~10 minutes.
#define SHT_SELF_HEAT_OFFSET_C 0.0f
#define CLOUD_BASE_SMOOTH_ALPHA 0.3f  // 0..1, lower = smoother (samples every SHT_SAMPLE_MS)
#define SHT_SAMPLE_MS 10000
extern Adafruit_SHTC3 shtc3;
extern bool shtc3OK;
extern float currentTempC;
extern float currentHumidityPct;   // raw SHTC3 relative humidity, %
extern float cloudBaseAboveM;      // smoothed estimate: metres from you up to cloud base (NAN = no estimate)
extern unsigned long lastShtSample;
void updateCloudBaseEstimate();

// =====================================================
// CLOCK / PCF85063 HARDWARE RTC
// =====================================================
// New Zealand timezone, including daylight saving.
#define NZ_TIMEZONE "NZST-12NZDT,M9.5.0,M4.1.0/3"
#define PCF85063_I2C_ADDR 0x51
extern PCF85063A rtc;
extern unsigned long lastRtcPush;
extern bool rtcOK;
extern bool clockSynced;
extern bool gpsClockSyncedThisBoot;
bool syncClockFromGPS();
bool utcTmToEpoch(const struct tm& utc, time_t& epoch);

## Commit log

2026-08-20 ESP32 Paragliding vario
    Uses a Waveshare RLCD dev board with an BMP580, LC76G GPS & HT-RA62 Lora module
2026-08-20 3D print files & PCB Files
    Only part of the 3D print files are here, need to finish the back. PCB files are complete. You can order through JLPCB or PCBWAY. Just upload the ZIP file
    [ESP32 vario-B_Cu.gbr, ESP32 vario-B_Mask.gbr, ESP32 vario-B_Paste.gbr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]
2026-08-22 Changed case dimensions.
    Modified the 3D print case to support the PCB plus added click tabs
    [Flight computer back plate.stl, Flight computer base plate.stl, Flight computer shell.stl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]
2026-08-24 Updated weather pages & ADSB pages
    Also adjusted the 3d print files, still need to make more adjustments
    [Flight computer back plate.stl, Flight computer base plate.stl, Flight computer main case.stl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]
2026-08-25 Adjusted 3D prints & changed ADSB page
    [Flight computer main case.stl]
2026-08-29 Added Kicad PCB layout
    Footprint for the RA62 is off by 0.01mm, need to adjust & update.
    [ESP32 vario-B_Cu.gbr, ESP32 vario-B_Mask.gbr, ESP32 vario-B_Paste.gbr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]
2026-08-29 Fixed more audio bugs
    [OpenAirScanner.cpp]
2026-09-06 Changed the 3D print files & added more menu items
    [Flight computer back plate.stl, Flight computer main case.stl]
2026-09-07 New PCB Layout
    Fully rebuilt PCB from scratch, LoRa module is now compatible with FANET, Key button to be moved to BOOT key. More work to do.
    [ESP32 vario-B_Cu.gbr, ESP32 vario-B_Mask.gbr, ESP32 vario-B_Paste.gbr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]
2026-09-07 Removed DIO18 as it conflicts with Key pin
    [ESP32 vario-B_Cu.gbr, ESP32 vario-B_Mask.gbr, ESP32 vario-B_Paste.gbr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]
2026-09-08 Added FANET
    PCB has been rebuilt, FANET test code has been written, now need to go do some real world testing. Still more menu changes to be made.
    [ESP32 vario-B_Cu.gbr, ESP32 vario-B_Mask.gbr, ESP32 vario-B_Paste.gbr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]
2026-09-11 print files tweaked a little
    [Flight computer base plate.stl, Flight computer main case.stl]
2026-09-11 More minor changes
    [Flight computer back plate.stl, Flight computer main case.stl]
2026-09-12 Added Bluetooth & wifi Menu
    [Flight computer back plate.stl]
2026-09-14 Reversed the startup sequence so it boots in 3 seconds instead of 15
    [wifi_manager.cpp]
2026-09-16 More bugs fixed
    Air space still not working. Might need to turn it into a DEM file.
    [menu.cpp]
2026-09-17 More bugs fixed
    FANET still left to fix
    [OpenAirScanner.cpp, Sx126xLink.cpp]
2026-09-18 FANET working, there is now a bug in the vario that needs fixed
    [Sx126xLink.cpp]
2026-09-21 Added option to export files via wifi
    [button_Long.stl, button_Short.stl]
2026-09-21 Added my 3d print buttons
2026-09-23 More changes to Vario & volume
    Should be fixed now.
    [menu.cpp]
2026-09-24 Fixed the header pins on the PCB
    Header pins have been moved closer by 1mm, should make it easier to solder.
    [ESP32 vario-B_Cu.gbr, ESP32 vario-B_Mask.gbr, ESP32 vario-B_Paste.gbr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]
2026-09-29 Me bug fixes, more to come
    [OpenAirScanner.cpp, Vario.cpp]
2026-10-01 QNH: start at 1013.25 on boot, update from GPS on first good fix, refresh every 15 min
    - qnhCalibrated/qnhIsFallback now default to true so altitude, vario, AGL
    etc. run immediately and nothing waits on GPS.
    - Remove the 60 s GPS timeout fallback block (GPS_QNH_FALLBACK_MS).
    - Fix averaging window never filling: gps.altitude.isUpdated() is cleared
    by loop()'s gps.altitude.feet() read, so detect new fixes via age().
    [Vario.cpp]
2026-10-01 Vario: decouple climb rate from QNH; add 1.5 s averaged climb rate for display
    - Climb-rate window now holds altitude from a fixed 1013.25 hPa reference,
    so a QNH update (first GPS calibration, 15-minute refresh) no longer adds
    a step to the samples and a spurious climb/sink spike. currentAltitudeM
    (display, AGL, logging) still uses the real QNH.
    - New currentClimbRateAvgMS: time-windowed mean of the fast climb rate over
    DISPLAY_CLIMB_AVG_MS (1500 ms). Used by the on-screen vario and glide
    ratio. The audio buzzer and FANET keep the fast currentClimbRateMS.
    - Unit tests for the average (steady, noise, window expiry, millis wrap).
    [Vario.cpp]
2026-10-04 Temp bug fix, to test later
    [IgcRecorder.cpp]
2026-10-05 More IGC bug fixing
    [IgcRecorder.cpp]
2026-10-05 Bug fix for speed. Added more buffer overflow.
    [FlightComputer.cpp]
2026-10-15 added engine meter battery symbol
2026-10-20 Added Kalman filtering for vario
    Need to do inflight testing.
2026-11-04 WiFi: Add Network phone portal and saved networks
    Let a pilot add a WiFi network from a phone, with no computer or reflash.
    - wifi_manager: keep up to 5 networks in NVS (own "wifisav" namespace) on top
    of secrets.h, with add, update and forget. One combined slot index, so
    selectedWifiIndex stays compatible. When all 5 are used, the oldest is
    replaced.
    - WifiSetup (new): Connections > WiFi > + Add Network scans, then starts a
    temporary open hotspot, Vario-Setup, with a DNS captive portal and a web form
    on 192.168.4.1. Runs in its own Core 0 task so Core 1 is never held up. Closes
    3 s after a save, or after 10 minutes idle, then connects.
    - menu: list only the networks that exist,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
2026-11-04 IGC: record a track point every 1 s (flush every 5 s)
    The old 4 s interval was too coarse for thermalling turns. One B-record per
    second matches the GPS fix rate.
    - Flush to the card at most every 5 s rather than after every record, so 1 Hz
    logging doesn't put an SD write on the main loop each second. A sudden power
    loss can cost at most that much track.
    - Size the pending queue for about 30 s of records (32, was 8).
    - README: state the recording rate.
2026-11-04 Redesign Add Network screen with WPA2 hotspot and QR codes
    - Protect the Vario-Setup hotspot with WPA2 (password shown on screen).
    - Show the two steps side by side, each with a same-size QR code, so the
    steps stay visible. Status has its own line and says which step is next.
    - Add a reminder to turn mobile data off if the page won't open, on the
    unit's screen because the setup page can't be reached when that happens.
    - Add tips to the phone page and update the README.
    Uses the QR encoder built into the ESP32 framework, so no new library.
2026-11-04 WIP: traffic page declutter
    - Add ADS-B Settings > Ground Traffic: Hide/Show (default Hide, saved in NVS).
    Hide aircraft reported on the ground, or below 200 ft and 40 kt. Never hide
    helicopters (A7) or FANET. This replaces the 10 kt filter for the display;
    voice and siren alerts still ignore anything below 10 kt.
    - Add ADS-B Settings > Labels: Relevant/All/Off (default Relevant, saved in
    NVS). Relevant labels aircraft within 7,000 ft. At most 8 labels: close
    traffic first, then the nearest. The rest show as icons.
    - Use a smaller bold label font (helvB10).
    - Draw compass letters and ring distances last, on small background boxes.
    - README: describe the new settings.
    Co-Authored-B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
2026-11-04 Add Flights screen listing recent recordings
    New Flight Recordings > Flights: the 12 most recent flights, newest first,
    with date, take-off time, duration, max altitude and best climb.
    - Keep a one-line summary of each recording in /FLIGHTS.CSV.
    - Most recordings end with the power going off, as Auto-Stop is off by
    default. So save a checkpoint to /FLIGHT.CUR once a minute, and file it at
    the next boot if there was no clean stop.
    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
2026-11-05 File server: send the file page in pieces to save memory
    With a delete button on every row, a card with many recordings could need
    more heap than is free, and failed String appends silently lose rows. Read
    the list into PSRAM and send the page in chunks. Output is unchanged.
2026-11-05 Don't stall when plugged into a PC with nothing reading serial
    The default 100 ms timeout lets each print wait up to 2 s with no reader,
    slowing the whole unit: file page loads took about 17 s instead of 0.4 s.
2026-11-05 Keep the serial log complete with the shorter USB wait
    A 1 ms wait lost most of the log, including start-up, even with a reader
    attached. A 2 KB transmit buffer holds the bursts; page loads stay fast with
    USB attached and nothing reading it.
